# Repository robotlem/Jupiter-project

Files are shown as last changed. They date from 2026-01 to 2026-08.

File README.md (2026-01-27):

# Jupiter-project

Ziel des Projektes ist es eine fortschrittliche Lichtkonsole zu entwickeln. Diese soll künftig mit intelligenten Assistenzfunktionen ausgestattet sein.

Andere Verwendungszwecke außerhalb der Lichttechnik, beispielsweise ein Audio Playback Betrieb, oder DAW Controller sind auch denkbar.

## Ordnerinhalt

Um ein möglichst geordnetes Projekt zu erhalten soll folgende Zuordnung weitestgehend eingehalten werden.

### Datasheets

Alle möglichen Unterlagen zu den Bauteilen; z.B. Datenblätter, Anleitungen, Handbücher

### Doku

Die Dokumentation des Projektes. Was wurde wie Konfiguriert? Backups der Einstellungen/Configs. Erarbeitung eines Handbuchs zur Konsole.

### Hardware

Alle Pläne die die Hardware betreffen. Unter anderem BOM (\*Bill Of Materials\*), Konstruktionszeichnungen, ECAD, Platinendesigns, 3D-Druck Modelle, … 

### Software

Alle selbst geschriebenen Softwaremodule/-komponenten. Software für die Mikrocontroller sowie für den Mac Mini.

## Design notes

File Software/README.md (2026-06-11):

# Softwarekomponenten

Hier befinden sich die verschiedenen Softwaremodule.

Die Struktur unterteilt sich in Hardware-Modul-Software und Mac Software.

## 010_Controller_Firmware

Dieser Ordner enthält die Firmware der einzelnen Controller. Im shared ordner liegen gemeinsamme daten, wie CAN-Bus Definitionen, ...

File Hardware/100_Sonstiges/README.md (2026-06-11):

# Chain
Source: https://www.thingiverse.com/thing:4597552

Skalliert auf Y-Achse auf 137,5%

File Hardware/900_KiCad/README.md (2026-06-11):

# 900_KiCad
Dieser Ordner enthält alle zusätzlichen von KiCad benötigten Dateien:
- SW_MX.kicad_mod: Bauteildefinition für Keyswitche (MX Style) https://github.com/daprice/keyswitches.pretty.git
- SK6812-Mini-E: Aus Keebio-Parts.pretty: https://github.com/keebio/Keebio-Parts.pretty/tree/master

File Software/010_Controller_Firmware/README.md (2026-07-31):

# Jupiter Controller Firmware

Firmware-Sammlung fuer ein modulares Lichtpult, das ETC Eos auf einem Mac mini
bedient. Die Bedienhardware wie Taster, Displays, Fader und Drehencoder ist als
verteiltes System ueber einen gemeinsamen CAN-Bus angebunden. Der Mac mini
haengt ueber einen USB-CAN-Adapter ebenfalls am Bus und uebernimmt spaeter die
Uebersetzung zwischen Hardwareereignissen und Eos.

Der aktuelle Stand ist ein PlatformIO-Workspace mit mehreren separaten
Firmware-Projekten. Die Firmware fuer die einzelnen Module liegt jeweils in
einem eigenen Unterordner; gemeinsame CAN-IDs liegen in `shared/sharedCommon`.

## Projektstruktur

| Ordner | Status | Zweck |
| --- | --- | --- |
| `FM01_Pico_Encoder` | aktiv | Raspberry Pi Pico 2 / RP2350 fuer fuenf Quadratur-Encoder, zwei MCP23S17-Tasterexpander, SK6812/NeoPixel-Test und CAN ueber `can2040`. |
| `FM02_ESP_Fader` | Prototyp | ESP32-S3-Firmware fuer Motorfader mit analoger Positionsmessung, Moving Average und PI/PID-artiger Motorregelung ueber DRV8833. Noch ohne CAN-Anbindung. |
| `FM03_ESP_Display` | aktiv/prototypisch | ESP32-S3-Displaymodul mit 800x480 RGB-Panel, LovyanGFX, LVGL und CAN-Textupdates ueber ESP-IDF-TWAI. |
| `PM02_ESP_Haptic_Encoder` | Prototyp | ESP32-S3-Firmware fuer haptische Encoder mit SimpleFOC, AS5600-Magnetsensor, BLDC-Treiber und LED-Test. CAN ist vorbereitet, aber auskommentiert. |
| `shared/sharedCommon` | aktiv | PlatformIO-Library mit zentralen CAN-Konstanten in `CAN_IDs.h`. |
| `ZZZZ_legacy` | Altstand | Aeltere Tests, Proof-of-Concepts und historische Kopien. Nicht als aktuelle Quelle behandeln. |

## Toolchain

Alle aktiven Projekte verwenden PlatformIO mit Arduino-Framework.

```bash
pio run -d FM01_Pico_Encoder -e encoder_1
pio run -d FM01_Pico_Encoder -e encoder_2
pio run -d FM02_ESP_Fader
pio run -d FM03_ESP_Display -e display_1
pio run -d FM03_ESP_Display -e display_2
pio run -d PM02_ESP_Haptic_Encoder
```

Upload und serieller Monitor laufen entsprechend ueber PlatformIO:

```bash
pio run -d FM01_Pico_Encoder -e encoder_1 -t upload
pio device monitor -d FM01_Pico_Encoder -b 115200
```

Die ESP32-S3-Projekte aktivieren USB-CDC im Build, daher erscheint die serielle
Konsole typischerweise direkt ueber den USB-Port.

## CAN-Bus

Die zentrale Protokolldatei ist:

```text
shared/sharedCommon/src/CAN_IDs.h
```

Aktuelle Busparameter:

| Parameter | Wert |
| --- | --- |
| CAN-Frameformat | Standard-ID, 11 Bit |
| Bitrate | 500 kbit/s |
| Heartbeat-Intervall | 3000 ms |
| Heartbeat-Timeout | 5000 ms |

Die kleinere CAN-ID hat auf dem Bus hoehere Prioritaet.

### Button-Events

| CAN-ID | Bedeutung |
| --- | --- |
| `0x200` bis `0x20F` | `CID_BUTTON_EVENT_GRP0` bis `CID_BUTTON_EVENT_GRP15` |

Laut Kommentar wird als Payload eine Buttonnummer erwartet; bei gedruecktem
Button ist das MSB gesetzt. In `FM01_Pico_Encoder` werden die beiden MCP23S17
bereits gelesen, Button-Events werden aber im aktuellen Code noch nicht auf den
CAN-Bus gesendet.

### Display-Kommandos

| CAN-ID | Name | Payload |
| --- | --- | --- |
| `0x501` | `CID_DISPLAY_SET_TEXT_HEADER` | `Display_ID`, `Text_ID`, `Text_Length` |
| `0x500` | `CID_DISPLAY_SET_TEXT_PAYLOAD` | bis zu 8 Bytes UTF-8-Text |
| `0x502` | `CID_DISPLAY_SET_BOX_COLOR` | `Display_ID`, `Box_ID`, `R`, `G`, `B` |
| `0x503` | `CID_DISPLAY_UPDATE` | `Display_ID`; `255` aktualisiert alle Displays |

`FM03_ESP_Display` implementiert Text-Header, Payload und Update. Die
Textdaten werden in einem lokalen Buffer gesammelt und erst mit
`CID_DISPLAY_UPDATE` sichtbar gemacht. `CID_DISPLAY_SET_BOX_COLOR` ist im Code
als Case vorhanden, aber noch nicht implementiert.

Die Display-UI ist in fuenf Sektionen mit jeweils 16 Label-IDs organisiert.
Eine `Text_ID` besteht praktisch aus `section * 16 + labelIndex`, gueltig von
`0x00` bis `0x4F`.

### Heartbeats

| CAN-ID | Modul |
| --- | --- |
| `0x700` | Mac / Host |
| `0x701` | RP Pico Encoder 0 |
| `0x702` | RP Pico Encoder 1 |
| `0x703` | ESP Fader 0 |
| `0x704` | ESP Fader 1 |
| `0x705` | ESP Display 0 |
| `0x706` | ESP Display 1 |
| `0x707` | ESP Keyboard |
| `0x708` bis `0x70A` | ESP Haptic 0 bis 2 |

## Modulstatus

### FM01 Pico Encoder

Das Pico-Modul ist aktuell der am weitesten integrierte Firmwarestand:

- Zielplattform: Raspberry Pi Pico 2 (`rpipico2`) mit Earle Philhower Arduino-Core.
- Zwei Build-Varianten: `encoder_1` und `encoder_2`; `encoder_2` setzt `SECOND_ENCODER`.
- Fuenf Quadratur-Encoder werden ueber PIO gelesen.
- CAN laeuft ueber `can2040` auf PIO0 mit 500 kbit/s.
- Heartbeat sendet je nach Build-Variante `0x701` oder `0x702`.
- Zwei MCP23S17 an SPI sind initialisiert, mit Hardware-Adressierung `0x00` und `0x01`.
- 32 SK6812/NeoPixel-LEDs werden aktuell mit Testfarben gesetzt.

Bekannte Einschraenkungen:

- Encoderpositionsaenderungen werden bisher nur seriell ausgegeben, nicht als CAN-Event gesendet.
- MCP23S17-Zustandsaenderungen werden seriell ausgegeben, aber noch nicht in `CID_BUTTON_EVENT_*` Frames umgesetzt.
- `src/config.h` enthaelt noch `CAN_BUS_BITRATE = 125000`; verwendet wird aber `CAN_BITRATE = 500000` aus `sharedCommon`.
- Der CAN-Empfang puffert nur die zuletzt empfangene Nachricht. Wenn mehrere Frames vor dem Auslesen eintreffen, kann eine aeltere Nachricht ueberschrieben werden.

Weitere Details stehen in `FM01_Pico_Encoder/README.md`. Dort ist der Build-
Abschnitt allerdings aelter als die aktuelle `platformio.ini`; die aktuellen
Environments heissen `encoder_1` und `encoder_2`.

### FM02 ESP Fader

Der Fader-Code ist ein lokaler Motorregelungs-Prototyp:

- Zielplattform: ESP32-S3 DevKitC-1 mit 32 MB Flash / 16 MB PSRAM-Konfiguration.
- Faderposition wird analog gelesen und ueber einen Moving Average geglaettet.
- Zielposition kommt momentan ueber einzelne serielle Zeichen.
- Motoransteuerung erfolgt per PWM ueber DRV8833.
- Reglerparameter `Kp` und `Tn` werden ueber zwei analoge Eingange gelesen.
- CAN, Heartbeat und Eos-Integration sind noch nicht vorhanden.

### FM03 ESP Display

Das Displaymodul verbindet LVGL-UI mit CAN-Kommandos:

- Zielplattform: ESP32-S3 DevKitC-1 mit 4 MB Flash / 8 MB OPI-PSRAM-Konfiguration.
- Display: 800x480 RGB-Panel ueber LovyanGFX.
- UI: LVGL 8.3, fuenf Fader-/Button-Sektionen mit insgesamt 80 Labels.
- CAN: ESP32-TWAI auf `GPIO17` TX und `GPIO18` RX, 500 kbit/s.
- Zwei Build-Varianten: `display_1` und `display_2`; `display_2` setzt `SECOND_DISPLAY`.
- Heartbeat sendet je nach Build-Variante `0x705` oder `0x706`.

Bekannte Einschraenkungen:

- Farbupdates fuer Boxen sind noch nicht implementiert.
- Touch ist im Displaytreiber vorbereitet, aber aktuell nicht als Eingabe in die Anwendung integriert.
- Das Display akzeptiert Textpayloads nur nach passendem Header fuer die eigene `DISPLAY_ID`.

### PM02 ESP Haptic Encoder

Der haptische Encoder ist derzeit ein SimpleFOC-Versuchsstand:

- Zielplattform: ESP32-S3 DevKitC-1 N32R8V.
- Zwei Motor-/LED-Kanaele sind im Code angelegt, aktiv genutzt wird aktuell nur Motor 0.
- AS5600-Magnetsensor wird ueber I2C gesucht und fuer Motor 0 initialisiert.
- SimpleFOC arbeitet in Torque/Voltage-Control.
- Der Code erzeugt eine virtuelle Rastung mit 24 Zaehnen, Daempfung und virtuellen Endanschlaegen.
- CAN-Pins sind in `pins.h` definiert und TWAI-Code ist als Kommentar vorhanden, aber nicht aktiv.

## Offene naechste Schritte

- Einheitliches Eventformat fuer Encoder, Fader und haptische Encoder definieren.
- Button-Mapping der MCP23S17-Eingaenge als CAN-Frames senden.
- Host-Software fuer den Mac mini dokumentieren oder in dieses Repository aufnehmen.
- Fader-Firmware an CAN anbinden: Positions-Istwert, Zielwert, Touch/Taster und Heartbeat.
- Display-Farbkommandos (`CID_DISPLAY_SET_BOX_COLOR`) implementieren.
- CAN-Empfang auf Modulen mit hoeherer Last auf Queue/Ringbuffer erweitern.
- Legacy-Ordner nach Bedarf archivieren oder aus dem aktiven Workspace entfernen.

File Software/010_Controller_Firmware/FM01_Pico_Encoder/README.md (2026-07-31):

# FM01 Pico Encoder

Firmware für den Raspberry Pi Pico 2 mit RP2350. Das Projekt liest fünf
Quadratur-Encoder über PIO ein, kommuniziert über einen mit `can2040`
implementierten CAN-Bus und steuert eine Kette kompatibler NeoPixel-LEDs.

## Projektaufbau

- `src/main.cpp`: Initialisierung und Anwendungslogik
- `src/config.h`: Pinbelegung und grundlegende Konfiguration
- `src/can_bus.h/.cpp`: CAN-Schnittstelle, Empfangspuffer und PIO0-IRQ
- `src/can2040.c/.h`: Low-Level-CAN-Implementierung
- `lib/rp2040-encoder-library`: angepasste PIO-Encoder-Library für RP2350

## Build

Das Projekt verwendet PlatformIO:

```bash
pio run -e pico2
```

Die erzeugte Firmware liegt unter:

```text
.pio/build/pico2/firmware.uf2
```

## Pinbelegung

| Funktion | GPIO |
|---|---:|
| Encoder 0 A/B | 6 / 7 |
| Encoder 1 A/B | 8 / 9 |
| Encoder 2 A/B | 10 / 11 |
| Encoder 3 A/B | 12 / 13 |
| Encoder 4 A/B | 14 / 15 |
| CAN TX | 16 |
| CAN RX | 17 |
| NeoPixel-Daten | 2 |
| SPI SCK | 18 |
| SPI MOSI | 19 |
| SPI MISO | 20 |
| SPI CS | 21 |
| MCP0 Interrupt | 5 |
| MCP1 Interrupt | 4 |

Die beiden Signale eines Encoders müssen auf aufeinanderfolgenden GPIOs
liegen. Der in `PioEncoder` angegebene Pin ist jeweils der A-Pin.

## PIO-Belegung

Der RP2350 besitzt drei PIO-Blöcke mit jeweils vier State Machines.

| PIO | State Machine | Verwendung |
|---|---|---|
| PIO0 | SM0 | CAN Synchronisation |
| PIO0 | SM1 | CAN Empfang |
| PIO0 | SM2 | CAN Bitmustervergleich |
| PIO0 | SM3 | CAN Senden |
| PIO1 | SM0 | Encoder 0 |
| PIO1 | SM1 | Encoder 1 |
| PIO1 | SM2 | Encoder 2 |
| PIO1 | SM3 | Encoder 3 |
| PIO2 | SM0 | Encoder 4 |
| PIO2 | SM1 | NeoPixel/FastLED |
| PIO2 | SM2 | frei |
| PIO2 | SM3 | frei |

### Warum FastLED auf PIO2/SM1 liegt

Die Encoder werden zuerst initialisiert. Dadurch sind alle State Machines von
PIO1 und SM0 von PIO2 belegt. Anschließend reserviert das CAN-Modul alle vier
State Machines von PIO0. FastLED sucht danach in der Reihenfolge PIO0, PIO1,
PIO2 nach einer freien State Machine und erhält PIO2/SM1.

FastLED benötigt für die gesamte LED-Kette nur eine State Machine und einen
DMA-Kanal. Die Anzahl der LEDs erhöht die Anzahl benötigter State Machines
nicht.

### PIO-Programmspeicher

Jeder PIO-Block besitzt 32 Instruktionsplätze:

- Das Encoderprogramm benötigt 24 Instruktionen und wird pro PIO nur einmal
  geladen.
- Das FastLED-NeoPixel-Programm benötigt auf PIO2 zusätzlich 4 Instruktionen.
- PIO2 verwendet damit 28 von 32 Instruktionsplätzen.

Auf PIO2 bleiben zwei State Machines frei, aber nur vier freie
Instruktionsplätze. Ein weiteres PIO-Programm muss daher sowohl in die freien
State Machines als auch in den verbleibenden Programmspeicher passen.

## CAN-Schnittstelle

Das CAN-Modul stellt drei Funktionen bereit:

```cpp
void canBusBegin();
bool canBusReceive(CanBusMessage &message);
bool canBusTransmit(const CanBusMessage &message);
```

`canBusReceive()` liefert die zuletzt im IRQ empfangene Nachricht. Wenn vor dem
Auslesen mehrere Nachrichten eintreffen, wird die vorherige Nachricht
überschrieben; es gibt aktuell keine Software-Warteschlange.

## MCP23S17

Die Klasse `Mcp23s17` konfiguriert einen SPI-Portexpander mit 16 Eingängen,
internen Pull-ups und Interrupt bei Eingangsänderung:

```cpp
#include "mcp23s17.h"

Mcp23s17 mcp0;
Mcp23s17 mcp1;

void setup() {
    mcp0.init(0, PIN_MCP0_INT);
    mcp1.init(1, PIN_MCP1_INT);
}

void loop() {
    const uint16_t inputs0 = mcp0.update();
    const uint16_t inputs1 = mcp1.update();
}
```

Die Adresse entspricht dem Zustand der Hardware-Adresspins `A2:A0` und muss
zwischen `0` und `7` liegen. Alle MCP23S17 teilen sich den in `config.h`
definierten Chip-Select-Pin; die Auswahl erfolgt über die aktivierte
Hardware-Adressdekodierung.

Der Rückgabewert von `update()` enthält `GPIOA` in Bit 0 bis 7 und `GPIOB` in
Bit 8 bis 15. Wegen der Pull-ups ist ein offener Eingang `1` und ein gegen
Masse geschalteter Eingang `0`.

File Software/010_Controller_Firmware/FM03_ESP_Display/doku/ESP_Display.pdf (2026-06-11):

# ESP_Display

Version 1.0 (28.05.2026)

Hier die Ideen zur Gestaltung des Displays.

Das Display ist, wie alle anderen Module, über ein CAN-Bus Interface angebunden. Als erstes Ziel soll die Firmware nur Daten anzeigen können, eine Option für Touchinputs und Rückmeldung an das Host-Programm soll aber offen gelassen werden.

Da die Text- und Gestaltungsdaten (z.B. Farben) mehr als 8-Byte (Maximale Framelänge im Standard CAN-Bus) lang sind ist es nötig ein Format zu wählen, das die Daten in mehreren Frames schickt. Dankbarerweise ist bei CAN bereits eine Datensicherungsschicht vorhanden, sodass man sich nur noch um einen Header kümmern muss, der die textId (informationen darüber, an welcher Stelle der Text steht) und die Länge des Textes enthält. Genaueres zu textIds und deren Aufbau weiter unten.

## Standard Bildschirm

Standard Bildschirm

16 Zeilen in 5 Spalten
In Hex durchnummeriert

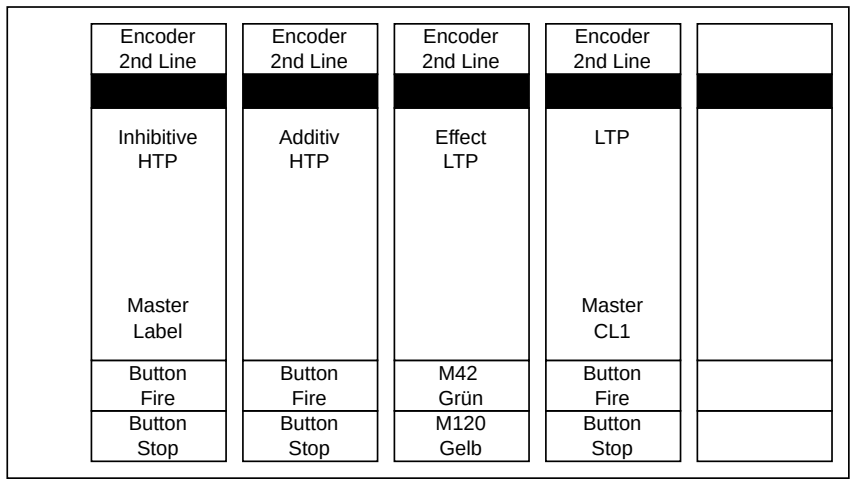
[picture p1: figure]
Encoder 2nd Line; Button Stop; Button Fire; Inhibitive HTP; Master Label; Additiv HTP; M120 Gelb; M42 Grün; Effect LTP; LTP; Master CL1
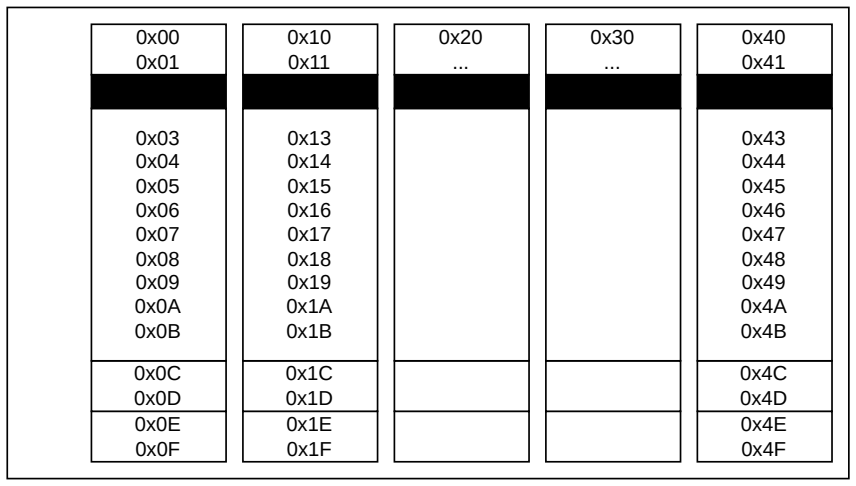
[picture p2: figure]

CAN Frame

Setzen der Kästen

Auch die Kästen haben IDs, mit denen Parameter wie Farbe gesetzt werden können

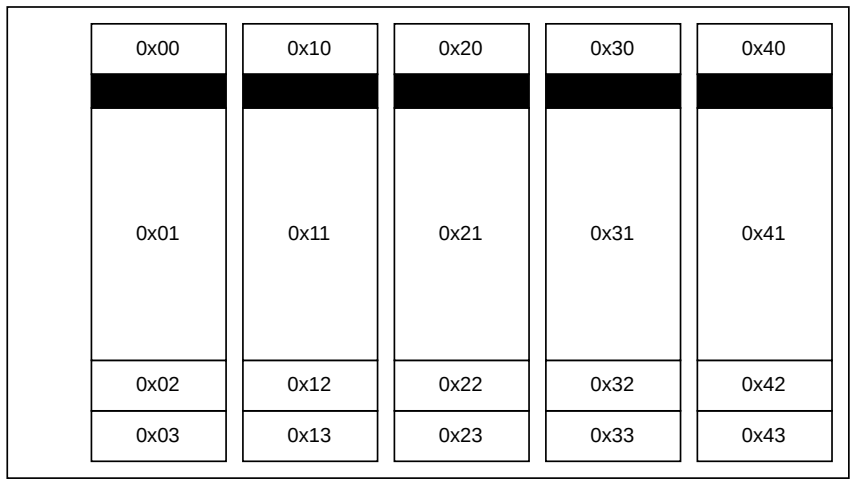
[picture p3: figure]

CAN Frame

CID_DISPLAY_SET_BOX_COLOR | Display_ID | Box_ID | R | G | B

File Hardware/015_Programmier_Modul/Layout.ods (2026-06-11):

Live | Snapshot |  | Help |  |  |  |  |  |  |  | Live | Blind | Stage
Blind | Fader |  | Address/ Patch |  |  |  |  |  |  |  | Displays |  | System
Stage | Macro |  | Learn | SK1 | SK2 | SK3 | SK4 | SK5 | SK6 | More SK | Undo |  | Scroll Lock
Displays |  |  |  | Query | Copy To | Recall From | Label |  | About | Park | Escape | PgUp | Select
System | Delete | Path | Effect | GoTo Cue | Block | Assert | Offset | High | Fan | Capture | PgLeft | PgDown | PgRight
M 801 | Part | Cue | Record | + | Thru | - | / | Mark | Sneak | Select Last | Tab | Find | Time
M 802 | Int Palette | Focus Palette | Record Only | 7 | 8 | 9 | Rem Dim | + % | Home | Select Manual | Format | Expand | Delta
M 803 | Color Palette | Beam Palette | Update | 4 | 5 | 6 | Out | - % | Trace | Select Active
M 804 | Preset | Sub | Group | 1 | 2 | 3 | Full | Level | Q Only Track | Last
M 805 | Shift | Delay | Time | Clear | 0 | . | At | Enter |  | Next

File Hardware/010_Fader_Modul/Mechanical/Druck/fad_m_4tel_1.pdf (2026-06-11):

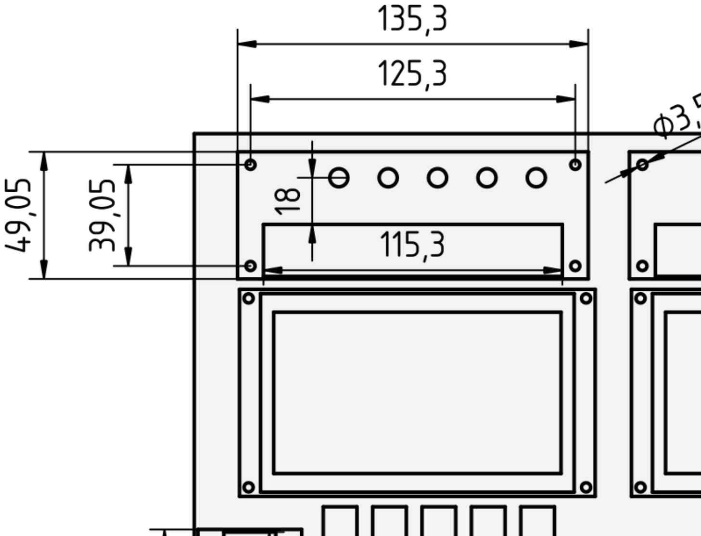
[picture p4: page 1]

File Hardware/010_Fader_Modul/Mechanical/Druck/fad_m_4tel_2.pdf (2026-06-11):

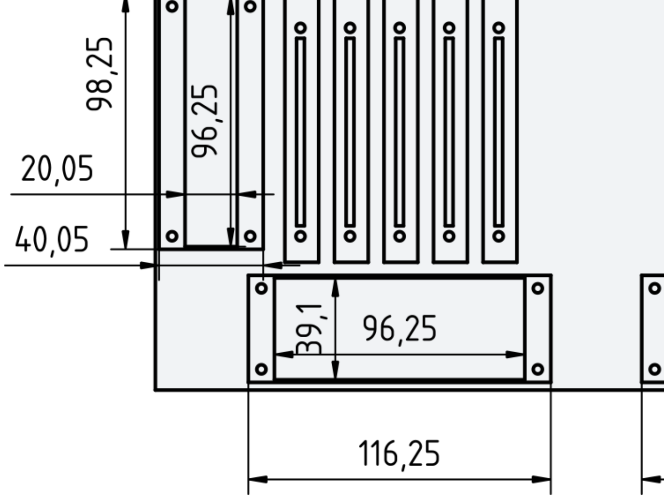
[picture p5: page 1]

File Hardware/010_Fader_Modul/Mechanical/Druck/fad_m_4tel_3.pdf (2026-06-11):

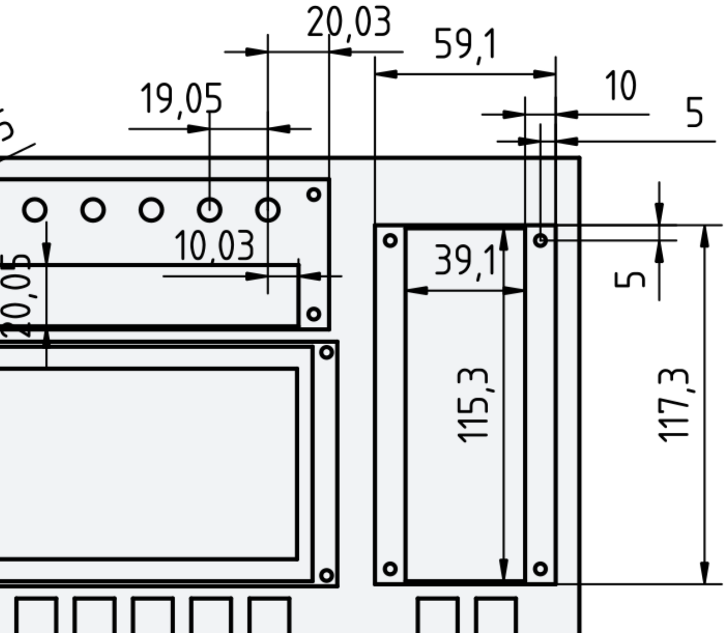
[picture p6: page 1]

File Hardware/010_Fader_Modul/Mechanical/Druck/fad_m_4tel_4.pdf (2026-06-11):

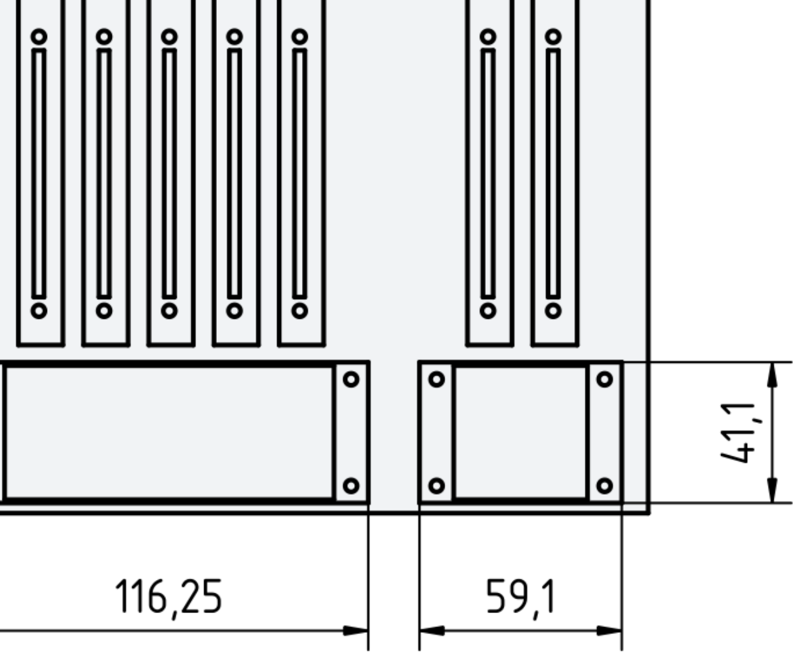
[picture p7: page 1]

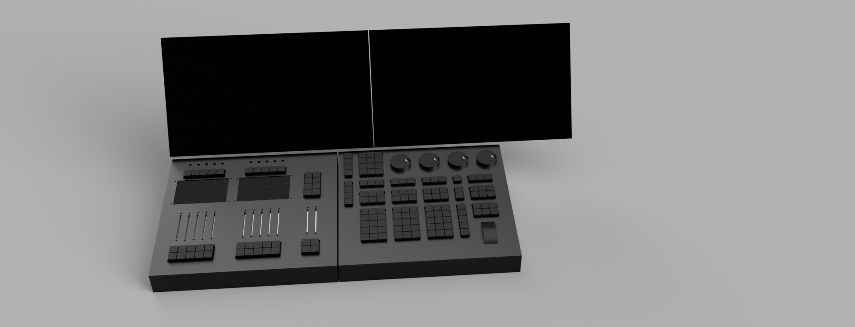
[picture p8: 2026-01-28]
Hardware/000_Uebersicht/9bad7475-ef7c-4377-8133-a8e182cbd2e1.PNG

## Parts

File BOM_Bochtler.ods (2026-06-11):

Bauteil | Artikelnummer | Anzahl | Preis stk. | Preis ges. |  | Händler | Link
Motorfader | 652-PSM60-081A-103B2 | 13 | 16,24 € | 211,12 € |  | Mouser | https://www.mouser.de/ProductDetail/652-PSM60-081A-103B2
Keyswitche | 540-MX3A-11NA | 170 | 0,86 € | 146,20 € |  | Mouser | https://www.mouser.de/ProductDetail/CHERRY/MX3A-11NA?qs=F5EMLAvA7ICizK1XKjfN9w%3D%3D
IO Expander | 579-MCP23S17-E/SO | 12 | 1,45 € | 17,40 € |  | Mouser | https://www.mouser.de/ProductDetail/Microchip-Technology/MCP23S17-E-SO?qs=usxtMOJb1RzJScThsWtScg%3D%3D
ESP32 S3 | 356-32S3DKTC1N32R16V | 6 | 13,66 € | 81,96 € |  | Mouser | https://www.mouser.de/ProductDetail/Espressif-Systems/ESP32-S3-DevKitC-1-N32R16V
Drehencoder | 652-PEC11R-4020F-N24 | 15 | 1,38 € | 20,70 € |  | Mouser | https://www.mouser.de/ProductDetail/Bourns/PEC11R-4020F-N0024?qs=Zq5ylnUbLm4a1Xa9DSXVvA%3D%3D
 |  |  |  | 0,00 €
 |  |  |  | 0,00 €
 |  |  |  | 0,00 €
 |  |  |  | 0,00 €
 |  |  |  | 0,00 €
 |  |  |  | 0,00 €
 |  |  |  | 0,00 €
 |  |  |  | 0,00 €
 |  |  |  | 477,38 €
 |  |  |  | + 19% | 568,08 € |  | (evtl. Zölle)

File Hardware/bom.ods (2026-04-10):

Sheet: Sheet1
 | Bauteil | Anzahl | Preis stk | Preis ges | Status
Grundlegend
 | Mac Mini (M4, 16GB RAM, 265GB SSD) | 1 | 579,00 € | 579,00 € | gekauft | apple.com → Studentenrabatt
 | Monitor Touch, 21,5“ | 2 | 266,67 € | 533,34 € | gekauft | https://www.galaxus.de/de/s1/product/iiyama-prolite-t2255msc-b1-1920-x-1080-pixel-2150-monitor-30378827
 | Anschlusskabel | 2 | 0,00 € | 0,00 € | inklusive
 | Tastatur | 1 | 53,99 € | 53,99 € | gekauft | https://www.amazon.de/dp/B0G3GK968S?ref=ppx_yo2ov_dt_b_fed_asin_title&th=1
 | USB C Hub | 1 | 8,99 € | 8,99 € | gekauft | https://www.amazon.de/dp/B07Q29N6H1?ref=ppx_yo2ov_dt_b_fed_asin_title&th=1
 | USB C auf B Kabel | 1 | 5,99 € | 5,99 € | gekauft | https://www.amazon.de/dp/B0DGX9YTBK?ref=ppx_yo2ov_dt_b_fed_asin_title&th=1
 |  |  |  | 0,00 €
 |  |  |  |  | https://www.mouser.de/ProductDetail/CHERRY/MX3A-11NA?qs=F5EMLAvA7ICizK1XKjfN9w%3D%3D
Fader Modul |  |  |  | 0,00 €
 | Motorisierte Schiebepotentiometer | 12 | 20,00 € | 240,00 € | THAB
 | Drehimpulsgeber | 10 | 2,00 € | 20,00 € | THAB | 652-PEC11R-4020F-N24
 | Keyswitche | 48 |  | 39,99 € | THAB | https://www.amazon.de/Glorious-Gaming-mechanische-Raptor-Tastaturschalter/dp/B0DCPFBS57?th=1 | 110
 | Motortreiber DRV8833 | 6 |  | 6,99 € |  | https://www.amazon.de/DRV8833-2-Kanal-DC-Motorantriebsplatine-Motorantriebs-Eingangsspannung/dp/B0DHRFRG6X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
 | MCP23S17 IO Expander | 3 | 1,53 € | 4,59 € | THAB
 | WS2812B | 48 |  | siehe unten | gekauft | https://www.amazon.de/SEZO-Individuell-Adressierbar-Nicht-Wasserdicht-Inneneinrichtung/dp/B09N99DJRG | 300
 | Weitere ICs, PCBs, Stecker, Kabel,... |  |  | 100,00 €
 |  |  |  | 0,00 €
Programming Modul |  |  |  | 0,00 €
 | Streamdeck | 1 | 199,00 € | 199,00 € | gekauft
 | Drehimpulsgeber | 5 | 2,00 € | 10,00 € | THAB
 | MCP23S17 IO Expander | 6 | 1,53 € | 9,18 € | THAB | https://www.mouser.de/ProductDetail/Microchip-Technology/MCP23S17-E-SP?qs=usxtMOJb1RyzobAZrBjFZA%3D%3D
 |  |  |  | 0,00 €
 |  |  |  | 0,00 €
 |  |  |  | 0,00 €
 | Keyswitche |  |  | 39,99 € |  | https://www.amazon.de/Glorious-Gaming-mechanische-Raptor-Tastaturschalter/dp/B0DCPFBS57?th=1 | 110
 | WS2812B |  |  | 22,99 € | gekauft | https://www.amazon.de/SEZO-Individuell-Adressierbar-Nicht-Wasserdicht-Inneneinrichtung/dp/B09N99DJRG
 | Weitere ICs, PCBs, Stecker, Kabel... | 1 | 100,00 € | 100,00 €
Gehäuse | Siebdruckplatten | 5 | 36,95 € | 184,75 € | gekauft
 | Vierkantrohr 25x25x2000 | 2 | 22,90 € | 45,80 € | gekauft
 | Vierkantrohr 20x20x2000 | 1 | 7,50 € | 7,50 € | gekauft
 | Flachstahl 30x6x2000 | 1 | 9,40 € | 9,40 € | gekauft
 | Schlossschrauben M8 | 1 | 6,59 € | 6,59 € | gekauft
 | Einfacauszug | 1 | 11,29 € | 11,29 € | gekauft
 | Nieten 4,8mm | 1 | 8,19 € | 8,19 € | gekauft
 | Nieten 4,8mm | 1 | 6,99 € | 6,99 € | gekauft
 | Nieten 4,8mm | 1 | 6,99 € | 6,99 € | gekauft
 | Sonstiges Case | 1 | 149,15 € | 149,15 € | gekauft
 | Servo Motoren | 1 | 11,99 € | 11,99 € | gekauft
 |  |  |  | 0,00 €
 |  |  |  | 0,00 €
 |  |  | Summe | 2.422,68 €
 |  |  |  |  |  | -422,68 €

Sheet: Sheet2
Case |  |  | stk | preis stk | summe
 | Kantenprofile | AH 1m | 10 | 3,9 | 39
 | Schlließprofile | 1m | 8 | 4,5 | 36
 | Kugelecken |  | 8 | 1 | 8
 | Butterfly |  | 4 | 6,5 | 26
 | Klappgriffe |  | 2 | 4,8 | 9,6
 |  |  |  |  | 0
 |  |  |  |  | 0
 |  |  |  |  | 0
 |  |  |  |  | 0
 |  |  |  |  | 0
 |  |  |  |  | 0
 |  |  |  |  | 0
 |  |  |  |  | 0
 |  |  |  |  | 0
 |  |  |  |  | 0
 |  |  |  |  | 0
 |  |  |  |  | 0
 |  |  |  |  | 0
 |  |  |  |  | 0
 |  |  |  |  | 118,6

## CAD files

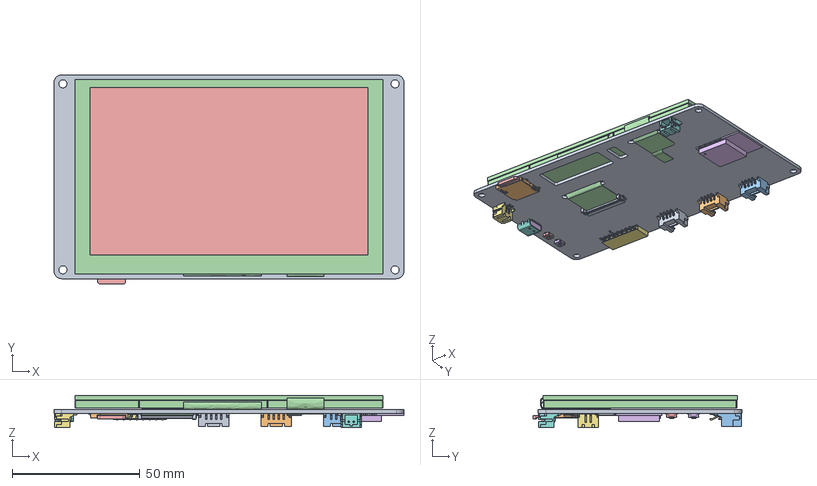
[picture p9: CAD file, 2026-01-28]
Datasheets/5Zoll_Screen.FCStd
137.2 x 82.0 x 12.6 mm
5IN-PCB-0221_A
BREP_1-383
BREP_2-384
BREP_8
BREP_9
BREP_10
BREP_11
BREP_12
BREP_13
BREP_14
BREP_15
BREP_16
BREP_17
BREP_18
BREP_19
BREP_20
BREP_21
BREP_22
BREP_23
BREP_24
BREP_25
BREP_26
BREP_27
BREP_31
BREP_33
BREP_32
BREP_034

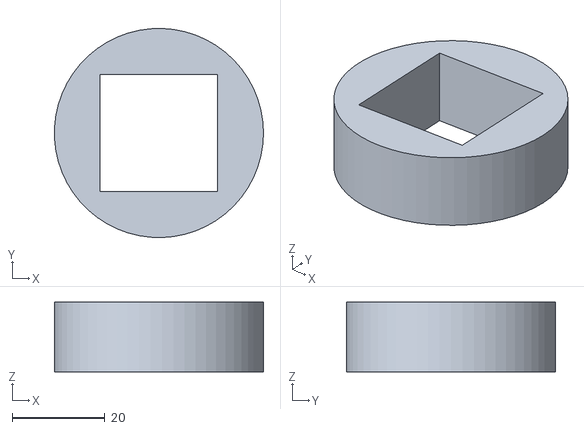
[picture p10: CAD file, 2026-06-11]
Hardware/005_Case/Fuerungen/Fuerung_Drehpunkt.stl
45.0 x 45.0 x 15.0

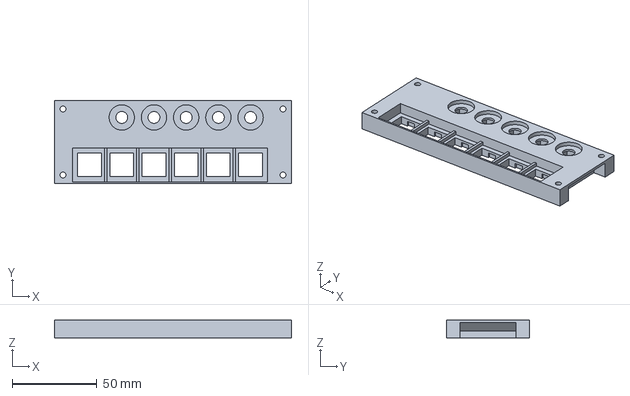
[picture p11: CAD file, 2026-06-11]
Hardware/010_Fader_Modul/Mechanical/3D-Druck/Fader_switch_holder_1x6_encoder.FCStd
140.2 x 49.0 x 10.5 mm

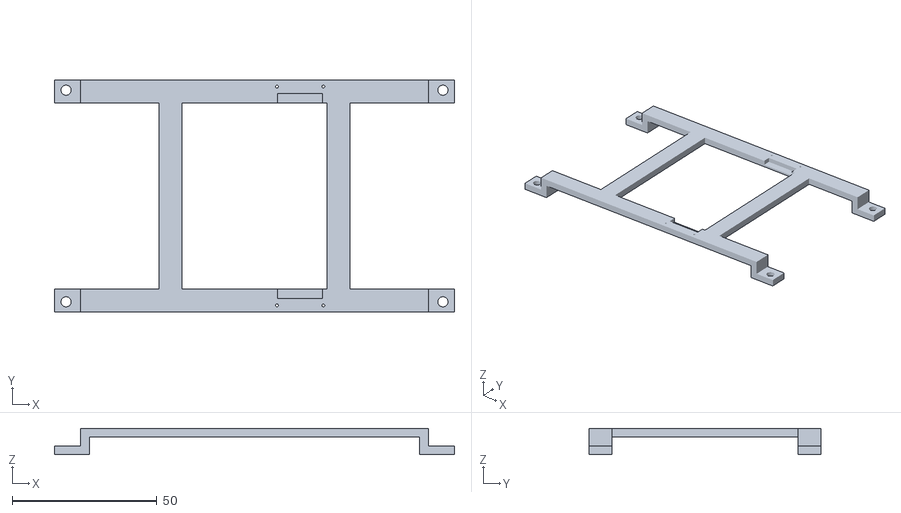
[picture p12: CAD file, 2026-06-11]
Hardware/010_Fader_Modul/Mechanical/Display_Can_adapter_holder-KörperPocket002.stl
138.0 x 80.0 x 9.00

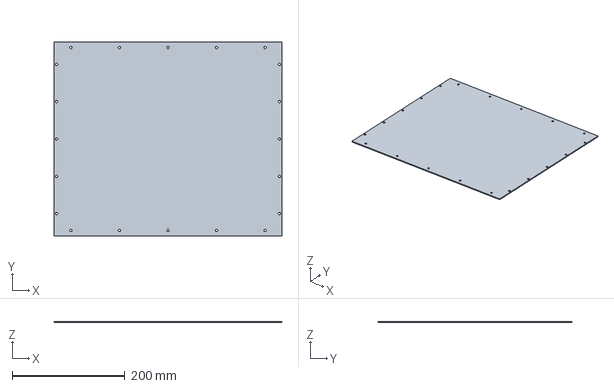
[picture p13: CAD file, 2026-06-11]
Hardware/015_Programmier_Modul/Front_plate_Programming.FCStd
405.0 x 345.0 x 2.00 mm

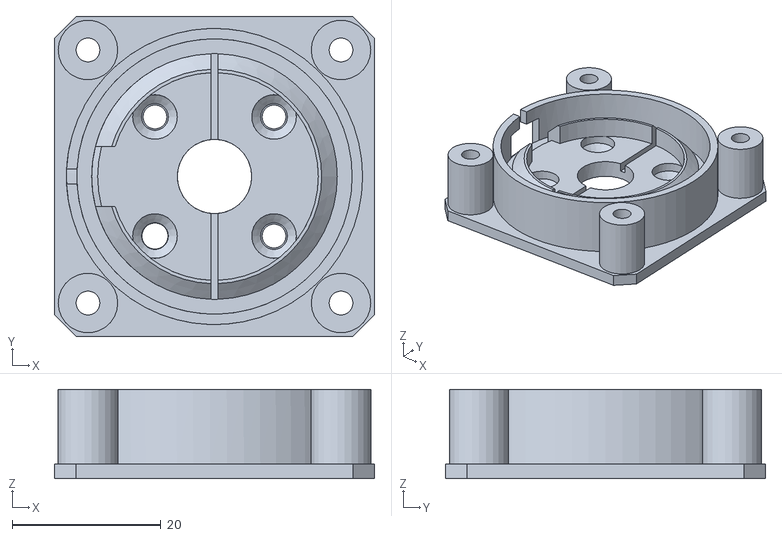
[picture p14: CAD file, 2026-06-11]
Hardware/025_Haptische_Encoder/Motorhalter_v2-1-KörperPocket008.stl
43.0 x 43.0 x 12.0

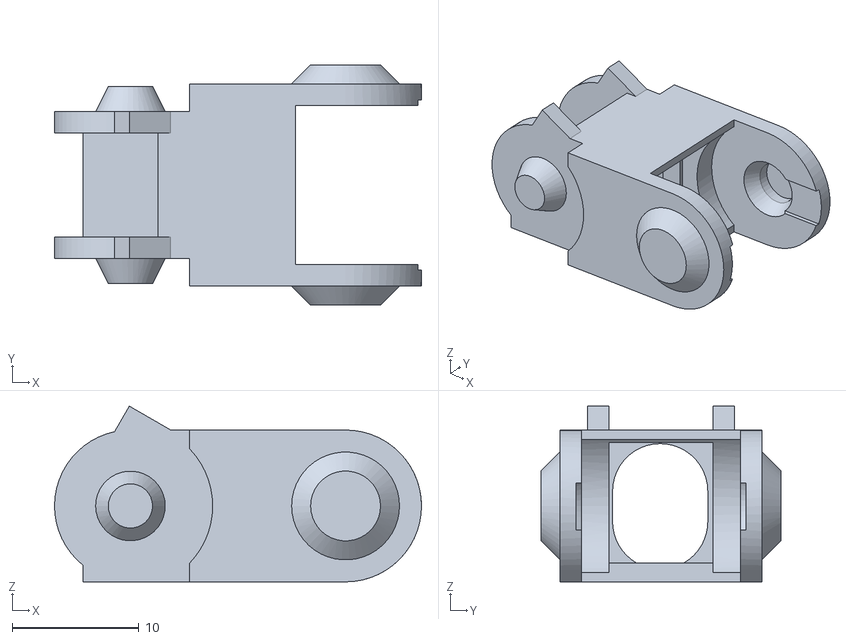
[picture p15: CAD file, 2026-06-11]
Hardware/100_Sonstiges/chain_link.stl
29.0 x 19.0 x 13.9

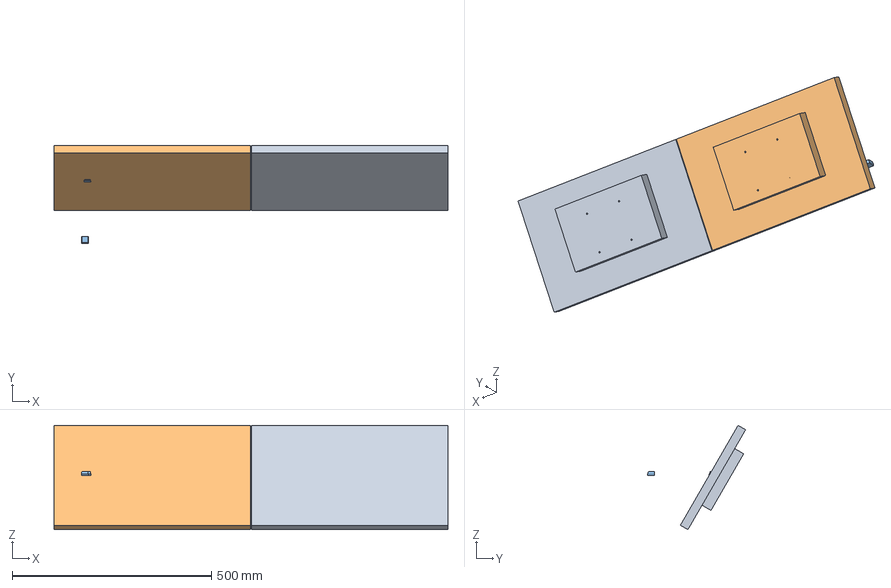
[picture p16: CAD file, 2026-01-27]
Hardware/Overview.FCStd
988.3 x 246.4 x 261.6 mm
Touchscreen1
Touchscreen2
keycap x 2

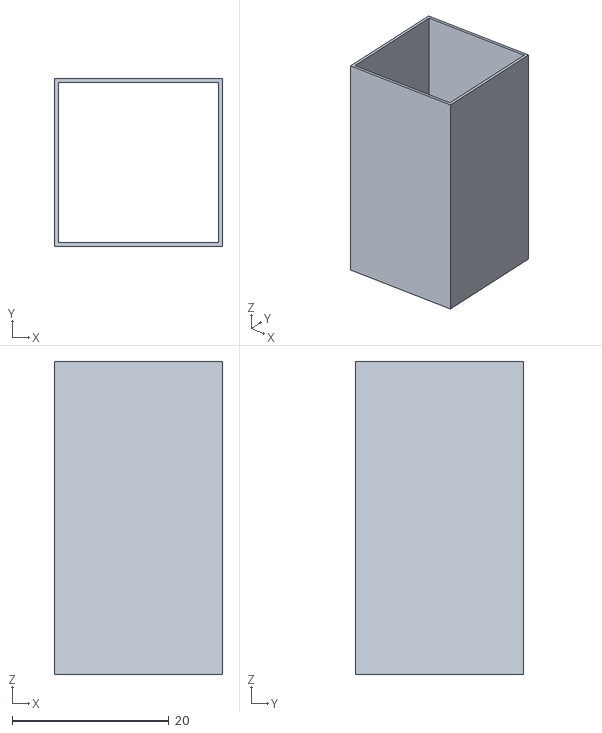
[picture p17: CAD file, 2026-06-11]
Hardware/005_Case/Fuerungen/Fuehrung_neu.stl
21.5 x 21.5 x 40.0

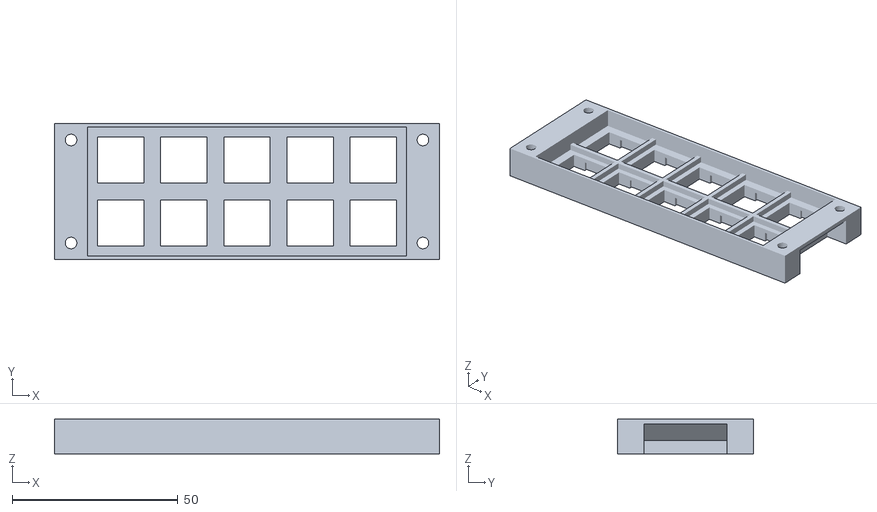
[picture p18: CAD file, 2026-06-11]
Hardware/010_Fader_Modul/Mechanical/3D-Druck/Fader_switch_holder-Körper001Chamfer.stl
116.2 x 41.1 x 10.5

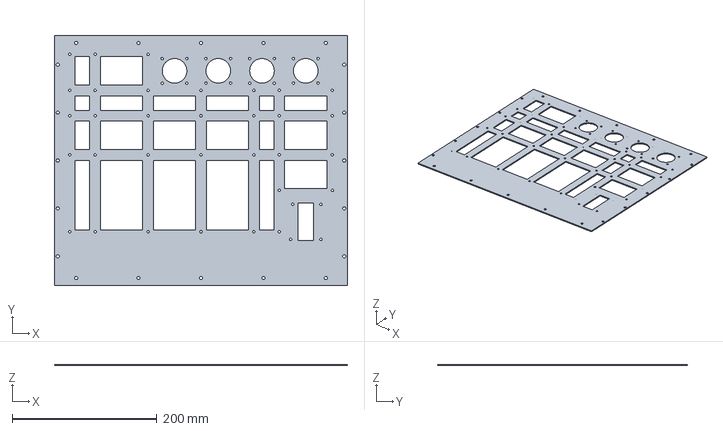
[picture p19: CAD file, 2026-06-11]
Hardware/015_Programmier_Modul/Front_plate_Programming_holes_only.FCStd
405.0 x 345.0 x 2.00 mm

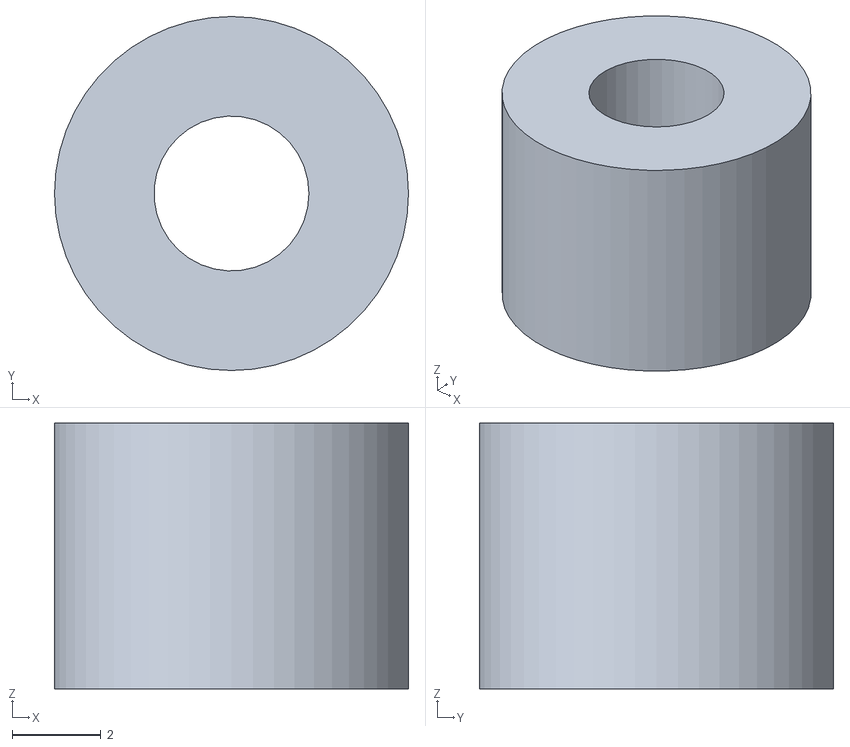
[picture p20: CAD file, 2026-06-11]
Hardware/025_Haptische_Encoder/spacer.stl
8.00 x 8.00 x 6.00

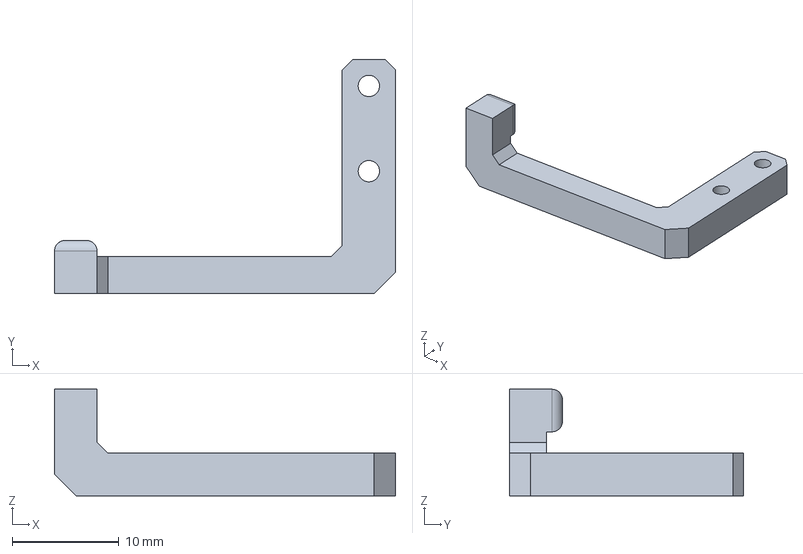
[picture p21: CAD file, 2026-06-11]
Hardware/100_Sonstiges/Mac_mini_servo_arm_2.FCStd
32.0 x 22.0 x 10.0 mm

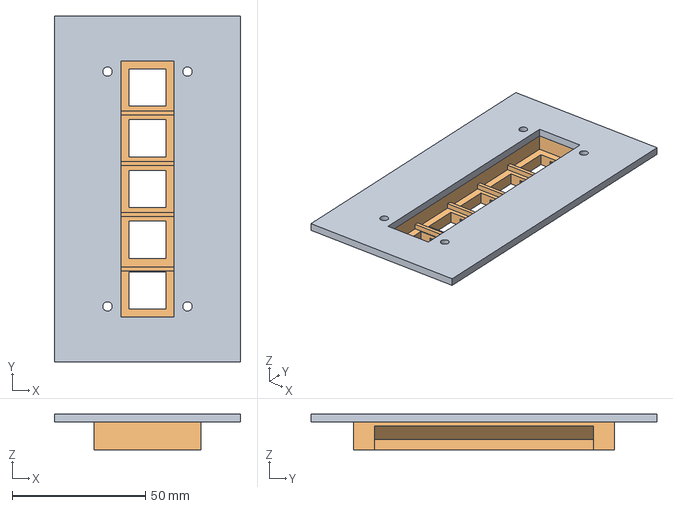
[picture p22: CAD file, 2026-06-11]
Hardware/010_Fader_Modul/Mechanical/3D-Druck/Fader_switch_holder_1x5.FCStd
70.0 x 130.0 x 13.5 mm
Körper
Körper001

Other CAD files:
Hardware/010_Fader_Modul/Mechanical/Display_Can_adapter_holder.FCStd
Hardware/005_Case/Fuerungen/Fuerung_neu.FCStd
Hardware/010_Fader_Modul/Mechanical/Front_plate_version2.FCStd
Hardware/015_Programmier_Modul/Programming_plate.dxf
Hardware/000_Uebersicht/Uebersicht.f3d
Hardware/005_Case/Fuerungen/Fuerung_Drehpunkt_v2.stl
Hardware/005_Case/Fuerungen/Fuerung_Gross.stl
Hardware/005_Case/Fuerungen/Fuerung_Klein.stl
Hardware/005_Case/Fuerungen/Fuerung_neu.stl
Hardware/005_Case/Fuerungen/Fuerungen.FCStd
Hardware/005_Case/Fuerungen/Fuerungen_Drehpunkt.stl
Hardware/010_Fader_Modul/Mechanical/3D-Druck/Fader_switch_holder.FCStd
Hardware/010_Fader_Modul/Mechanical/3D-Druck/Fader_switch_holder_1x5-Körper001Chamfer.stl
Hardware/010_Fader_Modul/Mechanical/3D-Druck/Fader_switch_holder_1x6_encoder-KörperChamfer.stl
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

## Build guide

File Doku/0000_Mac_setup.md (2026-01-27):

# Setup des Mac Mini

Es handelt sich um einen Mac Mini (2024) in der Basisausstattung (16GB RAM, 256GB SSD)

## Installierte Programme

- homebrew
- firefox
- touch-base Touchscreen Treiber (OEM Version) https://www.touch-base.com/oem/weida/
- texstudio
- mactex
- etc EOS
- spotify
- nextcloud client
- git
- Qt, Qt creator über Qt Online Installer
- CLion
- gcc
- Xcode: Ansonsten läuft qt nicht
- FreeCad

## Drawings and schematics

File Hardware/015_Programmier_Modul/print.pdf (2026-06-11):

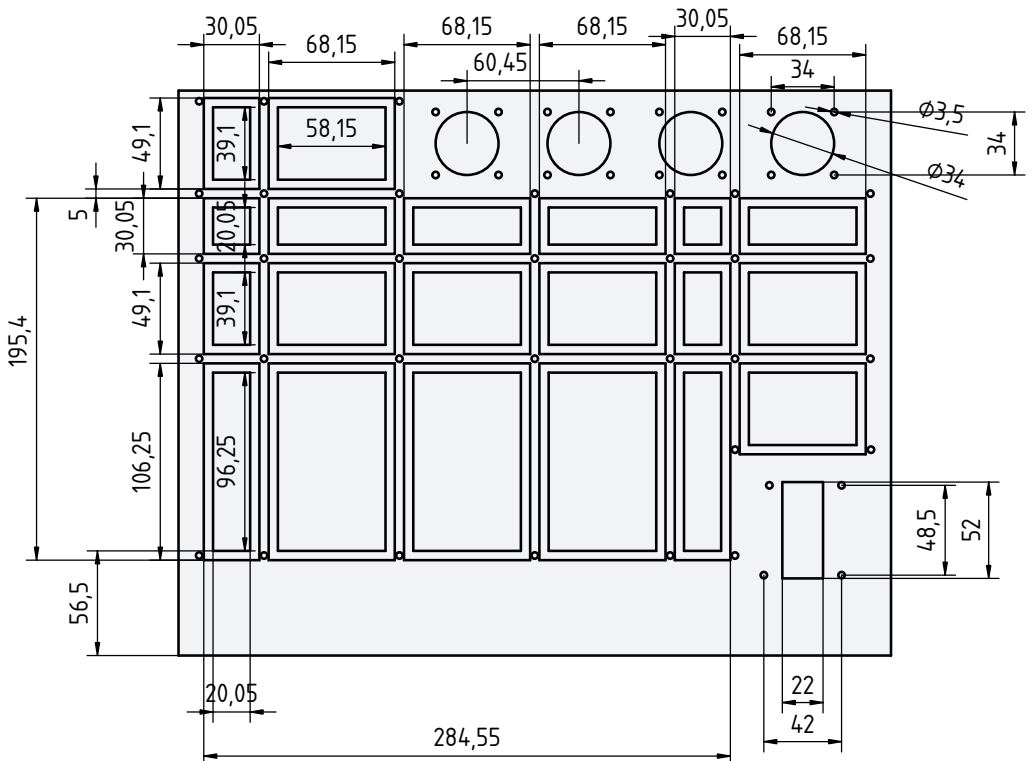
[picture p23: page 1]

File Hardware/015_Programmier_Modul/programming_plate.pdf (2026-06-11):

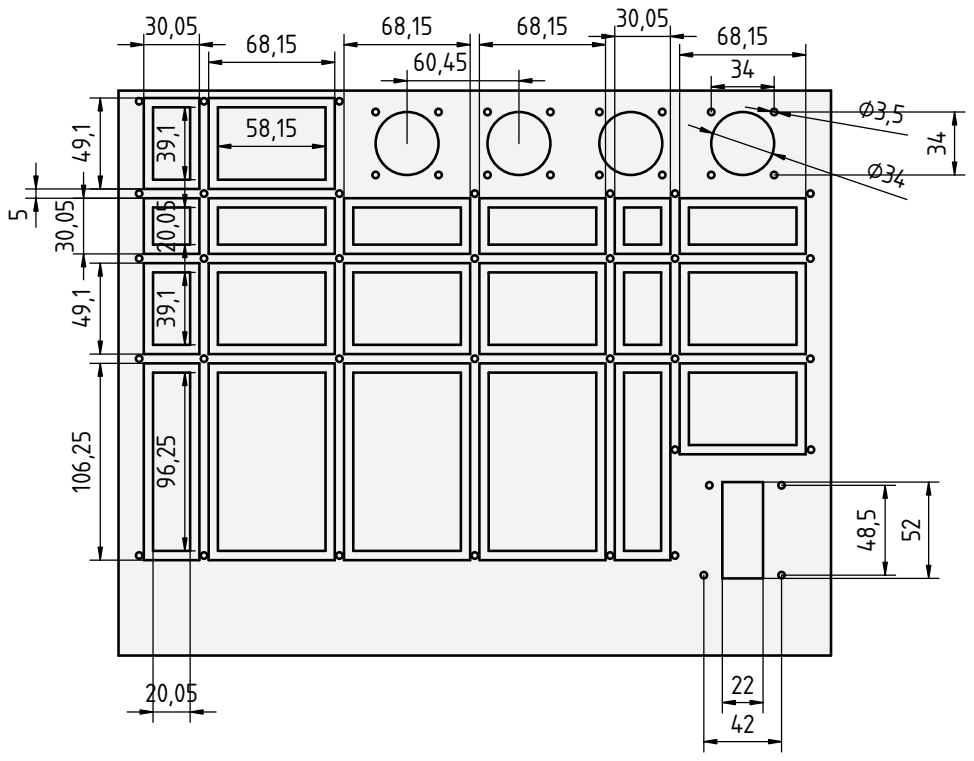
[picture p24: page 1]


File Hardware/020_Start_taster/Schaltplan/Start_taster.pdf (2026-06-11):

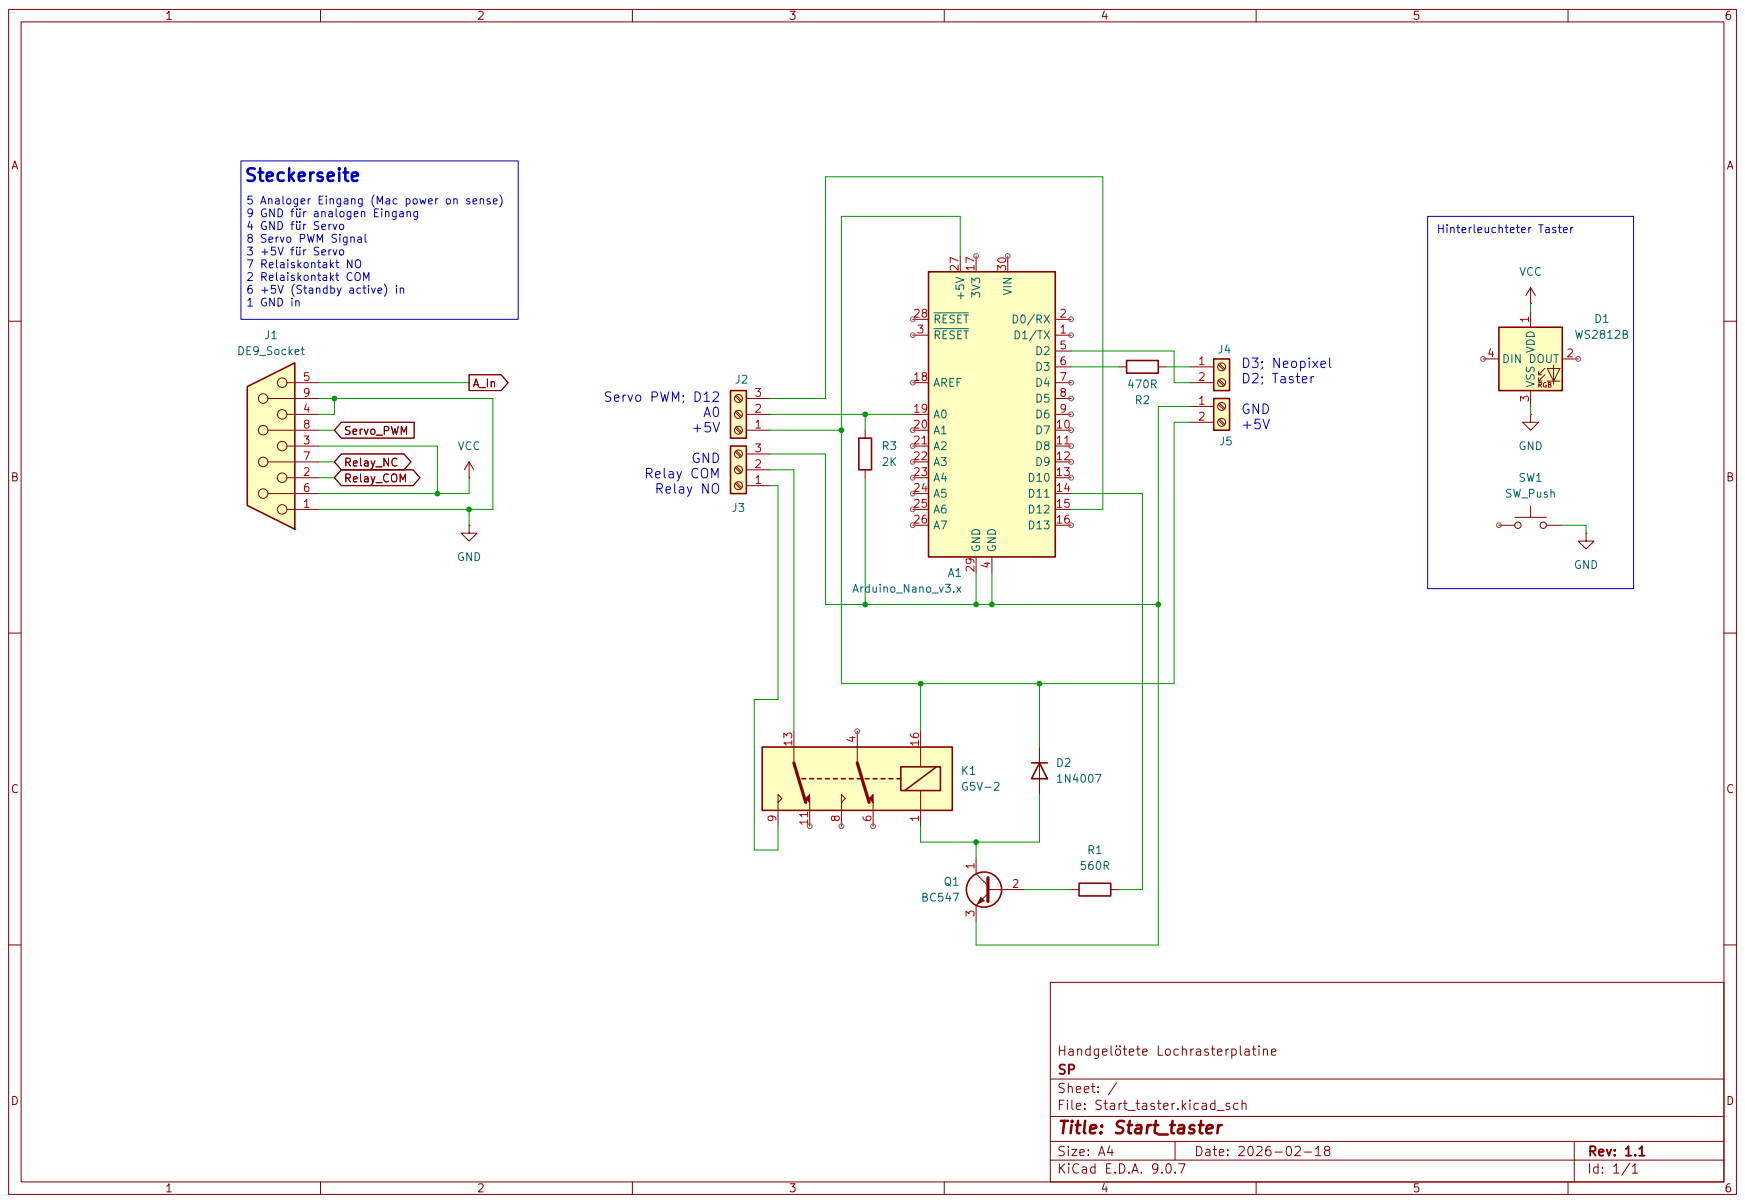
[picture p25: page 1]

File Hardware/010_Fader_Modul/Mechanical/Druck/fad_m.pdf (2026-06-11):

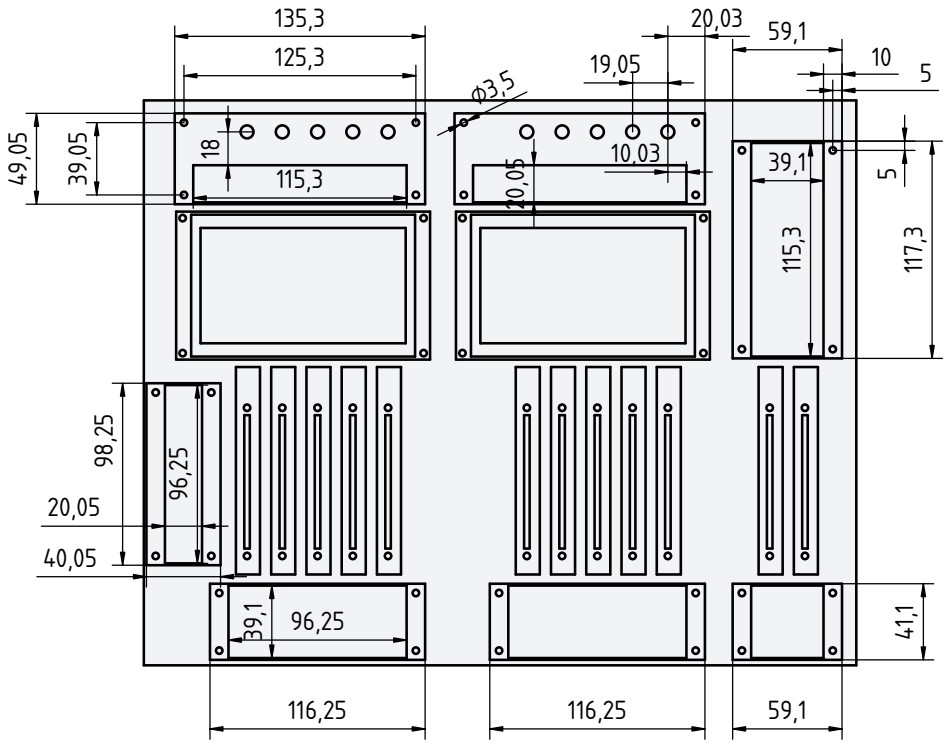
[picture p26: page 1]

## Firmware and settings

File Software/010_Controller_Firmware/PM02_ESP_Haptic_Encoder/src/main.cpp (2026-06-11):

#include <Arduino.h>
#include <FastLED.h>
#include <SimpleFOC.h>
//#include "driver/twai.h"
#include "pins.h"

#define NUM_LEDS 16

BLDCMotor motor0 = BLDCMotor(7);
BLDCDriver3PWM driver0 = BLDCDriver3PWM(DRV0_IN1, DRV0_IN2, DRV0_IN3, DRV0_EN);
MagneticSensorI2C sensor0 = MagneticSensorI2C(0x36, 12, 0x0E, 4);

BLDCMotor motor1 = BLDCMotor(7);
BLDCDriver3PWM driver1 = BLDCDriver3PWM(DRV1_IN1, DRV1_IN2, DRV1_IN3, DRV1_EN);
MagneticSensorI2C sensor1 = MagneticSensorI2C(0x36, 12, 0x0E, 4);

TwoWire I2C_0 = TwoWire(0);
TwoWire I2C_1 = TwoWire(1);

CRGB leds0[NUM_LEDS];
CRGB leds1[NUM_LEDS];

void setup() {
// write your initialization code here
    Serial0.begin(115200);

    FastLED.addLeds<NEOPIXEL, LED0_OUT>(leds0, NUM_LEDS);
    FastLED.addLeds<NEOPIXEL, LED1_OUT>(leds1, NUM_LEDS);

    for (int i = 0; i < NUM_LEDS; i++) {
        leds0[i] = CRGB::Green;
        leds1[i] = CRGB::Blue;

    }
    FastLED.setBrightness(255);

    FastLED.show();


    // twai_general_config_t g_config = TWAI_GENERAL_CONFIG_DEFAULT(CAN_TX, CAN_RX, TWAI_MODE_NORMAL);
    // twai_timing_config_t t_config = TWAI_TIMING_CONFIG_500KBITS();  // Baudrate anpassen
    // twai_filter_config_t f_config = TWAI_FILTER_CONFIG_ACCEPT_ALL();
    // if (twai_driver_install(&g_config, &t_config, &f_config) != ESP_OK) {
    //     Serial0.println("TWAI install failed!");
    //     return;
    // }
    // if (twai_start() != ESP_OK) {
    //     Serial0.println("TWAI start failed!");
    //     return;
    // }
    // Serial0.println("CAN ready!");

    I2C_0.begin(I2C0_SDA, I2C0_SCL, 100000);
    //I2C_1.begin(I2C1_SDA, I2C1_SCL, 100000);

    for(uint8_t addr=1; addr<127; addr++) {
        I2C_0.beginTransmission(addr);
        uint8_t err = I2C_0.endTransmission();

        if(err == 0) {
            Serial.printf("Found I2C device: 0x%02X\n", addr);
        }
    }

    SimpleFOCDebug::enable(&Serial0);

    sensor0.init(&I2C_0);
    motor0.linkSensor(&sensor0);
    //sensor1.init(&I2C_1);
    //motor1.linkSensor(&sensor1);

    driver0.voltage_power_supply = 12;
    driver0.init();
    motor0.linkDriver(&driver0);
    // driver1.voltage_power_supply = 12;
    // driver1.init();
    // motor1.linkDriver(&driver1);

    motor0.controller = MotionControlType::torque;
    motor0.torque_controller = TorqueControlType::voltage;
    // motor1.controller = MotionControlType::torque;
    // motor1.torque_controller = TorqueControlType::voltage;

    motor0.monitor_downsample = 50; // disable intially
    motor0.monitor_variables = _MON_TARGET | _MON_VEL | _MON_ANGLE; // monitor target velocity and angle
    motor0.voltage_limit = 6;
    motor0.velocity_limit = 10;
    motor0.P_angle.P = 2;   // kleiner = weicher
    // motor1.monitor_downsample = 50; // disable intially
    // motor1.monitor_variables = _MON_TARGET | _MON_VEL | _MON_ANGLE; // monitor target velocity and angle
    // motor1.voltage_limit = 6;
    // motor1.velocity_limit = 10;
    // motor1.P_angle.P = 2;   // kleiner = weicher

    motor0.PID_velocity.P = 0.15;
    motor0.PID_velocity.I = 0.5;
    motor0.PID_velocity.D = 0.0;
    motor0.LPF_velocity.Tf = 0.05;
    // motor1.PID_velocity.P = 0.15;
    // motor1.PID_velocity.I = 0.5;
    // motor1.PID_velocity.D = 0.0;
    // motor1.LPF_velocity.Tf = 0.05;


    // initialise motor
    // if (!motor0.initFOC()) {
    //     Serial0.println("motor0 FOC init FAILED");
    //     while(1);
    // }
    // if (!motor1.initFOC()) {
    //     Serial0.println("motor1 FOC init FAILED");
    //     while(1);
    // }

    // align encoder and start FOC
    motor0.initFOC();
    motor0.target = motor0.shaft_angle;
    // motor1.initFOC();
    // motor1.target = motor1.shaft_angle;



}

void loop() {
// write your code here


    motor0.loopFOC();

    float angle = motor0.shaft_angle;
    float velocity = motor0.shaft_velocity;

    float torque = 0;

    // Beispiel: 24 Rastungen
    int teeth = 24;
    float step = _2PI / teeth;
    float nearest = round(angle / step) * step;
    float error = angle - nearest;
    torque = - error*error * 120.0;
    if (error < 0) torque = -torque;

    // leichte Dämpfung
    torque -= velocity * 0.02;

    // virtuelle Endanschläge
    float limit = 2 * _2PI;
    float wall_stiffness = 40.0;

    if (angle > limit) {
        torque = -(angle - limit) * wall_stiffness;
    }

    if (angle < -limit) {
        torque = -(angle + limit) * wall_stiffness;
    }



    torque = constrain(torque, -motor0.voltage_limit, motor0.voltage_limit);
    motor0.move(torque);

    //
    //
    // {
    //     motor1.loopFOC();
    //
    //     float angle = motor1.shaft_angle;
    //     float velocity = motor1.shaft_velocity;
    //
    //     float torque = 0;
    //
    //     // Beispiel: 24 Rastungen
    //     int teeth = 24;
    //     float step = _2PI / teeth;
    //     float nearest = round(angle / step) * step;
    //     float error = angle - nearest;
    //     torque = - error*error * 120.0;
    //     if (error < 0) torque = -torque;
    //
    //     // leichte Dämpfung
    //     torque -= velocity * 0.02;
    //
    //     // virtuelle Endanschläge
    //     float limit = 2 * _2PI;
    //     float wall_stiffness = 40.0;
    //
    //     if (angle > limit) {
    //         torque = -(angle - limit) * wall_stiffness;
    //     }
    //
    //     if (angle < -limit) {
    //         torque = -(angle + limit) * wall_stiffness;
    //     }
    //
    //
    //
    //     torque = constrain(torque, -motor1.voltage_limit, motor1.voltage_limit);
    //     motor1.move(torque);
    // }
}

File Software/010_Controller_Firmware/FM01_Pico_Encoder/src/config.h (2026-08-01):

//
// Created by robo on 19.05.26.
//

#ifndef ZA_TEST_ENCODER_RPI_CONFIG_H
#define ZA_TEST_ENCODER_RPI_CONFIG_H

#include "Arduino.h"
#include <CAN_IDs.h>

// --- CAN CONFIGURATION ---    // CAN Läuft auf PIO 0
const int CAN_TX_PIN = 16;           // Beliebige freie GPIOs wählbar
const int CAN_RX_PIN = 17;

#ifdef SECOND_ENCODER
const uint16_t  CID_ENCODER_EVENT   = CID_ENCODER_EVENT_GRP1;
const uint16_t  CID_BUTTON_EVENT    = CID_BUTTON_EVENT_GRP1;
const uint16_t  CID_HEARTBEAT       = CID_HEARTBEAT_RPI_ENCODER_1;
#else
const uint16_t  CID_ENCODER_EVENT   = CID_ENCODER_EVENT_GRP0;
const uint16_t  CID_BUTTON_EVENT    = CID_BUTTON_EVENT_GRP0;
const uint16_t  CID_HEARTBEAT       = CID_HEARTBEAT_RPI_ENCODER_0;
#endif

// --- Encoder Configuration ---
const uint8_t PIN_ENC0 = 6;     // PIO 1
const uint8_t PIN_ENC1 = 8;     // PIO 1
const uint8_t PIN_ENC2 = 10;    // PIO 1
const uint8_t PIN_ENC3 = 12;    // PIO 1

const uint8_t PIN_ENC4 = 14;    // PIO 2
//Encoder Update Intervall in encoder.h

// --- SPI Configuration ---
const uint8_t PIN_SPI_SCK  = 18;
const uint8_t PIN_SPI_MOSI = 19;
const uint8_t PIN_SPI_MISO = 20;
const uint8_t PIN_SPI_CS   = 21;

// --- MCP23S17 Configuration ---
const uint8_t PIN_MCP0_INT = 5;
const uint8_t PIN_MCP1_INT = 4;

// --- SK6812 Mini-E Configuration ---
const uint8_t LED_PIN = 2;

// How to get the Index of the local LED Array from LED_ID?
// 1. Check for range: if (LED_ID-LED_OFFSET > LED_MAX_ID || LED_ID-LED_OFFSET < 0) return;
// 2. Get local Array Index: LED_MAPPING(LED_ID - LED_OFFSET)
// Check Result: 255 = invalid

#ifdef SECOND_ENCODER
const uint8_t NUM_LEDS = 32;
const uint8_t LED_OFFSET = 0;
const uint8_t LED_MAX_ID = 52;
const uint8_t LED_MAPPING[] = {
// 0    1    2    3    4      5    6    7    8    9
  255, 255, 255, 255, 255,   255,   0,   1,   2,   3, //  0 -   9
    4,   5, 255, 255, 255,   255, 255, 255, 255, 255, // 10 -  19
   255, 255, 255, 255, 255,  255, 255,  22,  23,  24, // 20 -  29
    25,  26,  27,  28,  29,   30,  31,   6,   7,   8, // 30 -  39
     9,  10,  11,  12,  13,   14,  15,  16,  17,  18, // 40 -  49
    19,  20,  21
};
#else
const uint8_t NUM_LEDS = 27;
const uint8_t LED_OFFSET = 0;
const uint8_t LED_MAX_ID = 26;
const uint8_t LED_MAPPING[] = {
      0,   1,   2,   3,   4,     5, 255, 255, 255, 255, //  0 -   9
    255, 255,   6,   7,   8,     9,  10,  11,  12,  13, // 10 -  19
     14,  15,  16,  17,  18,    19,  20, 255, 255, 255  // 20 -  29
};
#endif

#endif //ZA_TEST_ENCODER_RPI_CONFIG_H

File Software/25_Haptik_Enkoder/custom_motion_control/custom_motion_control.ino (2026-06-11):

#include <Arduino.h>
#include <SimpleFOC.h>

#define PID_vel_P
#define PID_vel_I
#define PID_vel_D


BLDCMotor motor = BLDCMotor(7);
//BLDCDriver3PWM driver = BLDCDriver3PWM(19, 18, 5, 17);
//MagneticSensorI2C sensor = MagneticSensorI2C(0x36, 12, 0x0E, 4);

BLDCDriver3PWM driver = BLDCDriver3PWM(14, 13, 12, 11);
MagneticSensorI2C sensor = MagneticSensorI2C(0x36, 12, 0x0E, 4);

void setup() {
  //Wire.begin(21, 22); 
  Wire.begin(41, 42); 
  Wire.setClock(400000);

  Serial.begin(115200);
  SimpleFOCDebug::enable(&Serial);

  // initialize sensor hardware
  sensor.init();
  motor.linkSensor(&sensor);

  // driver config
  driver.voltage_power_supply = 12;
  driver.init();
  motor.linkDriver(&driver);

  // set control loop type to be used
  motor.controller = MotionControlType::torque;
  motor.torque_controller = TorqueControlType::voltage;

  // comment out if not needed
  //motor.useMonitoring(Serial);
  motor.monitor_downsample = 50; // disable intially
  motor.monitor_variables = _MON_TARGET | _MON_VEL | _MON_ANGLE; // monitor target velocity and angle
  motor.voltage_limit = 6;
  motor.velocity_limit = 10;
  motor.P_angle.P = 2;   // kleiner = weicher

  motor.PID_velocity.P = 0.15;
  motor.PID_velocity.I = 0.5;
  motor.PID_velocity.D = 0.0;

  motor.LPF_velocity.Tf = 0.05;

  // initialise motor
  motor.init();

  // align encoder and start FOC
  motor.initFOC();
  motor.target = motor.shaft_angle;


  _delay(1000);
}

void loop() {
  // iterative setting FOC phase voltage
  motor.loopFOC();

  float angle = motor.shaft_angle;
  float velocity = motor.shaft_velocity;

  float torque = 0;

  // Beispiel: 24 Rastungen
  int teeth = 24;
  float step = _2PI / teeth;
  float nearest = round(angle / step) * step;
  float error = angle - nearest;
  torque = - error*error * 120.0;
  if (error < 0) torque = -torque;

  // leichte Dämpfung
  torque -= velocity * 0.02;

  // virtuelle Endanschläge
  float limit = 2 * _2PI;
  float wall_stiffness = 40.0;

  if (angle > limit) {
    torque = -(angle - limit) * wall_stiffness;
  }

  if (angle < -limit) {
    torque = -(angle + limit) * wall_stiffness;
  }
  


  torque = constrain(torque, -motor.voltage_limit, motor.voltage_limit);
  motor.move(torque);


}

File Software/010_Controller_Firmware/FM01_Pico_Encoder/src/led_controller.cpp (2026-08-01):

#include "led_controller.h"

#include <CAN_IDs.h>

#include "config.h"

LedController::LedController(CRGB leds[], uint8_t ledCount) {
    this->leds = leds;
    this->ledCount = ledCount <= NUM_LEDS ? ledCount : NUM_LEDS;
}

void LedController::begin() {
    FastLED.addLeds<NEOPIXEL, LED_PIN>(leds, ledCount);
    FastLED.setBrightness(255);
    fill_solid(pendingColors, ledCount, CRGB::Black);
    fill_solid(activeColors, ledCount, CRGB::Black);
    fill_solid(renderedColors, ledCount, CRGB::Black);
    fill_solid(leds, ledCount, CRGB::Black);
    blinkStartMs = millis();
    warningBlinkStartMs = blinkStartMs;
    lastHostHeartbeatMs = blinkStartMs;
    nextBlinkRenderMs = blinkStartMs;
    FastLED.show();
}

void LedController::update() {
    const unsigned long now = millis();
    updateHostHeartbeatState(now);

    if (static_cast<long>(now - nextBlinkRenderMs) < 0) {
        return;
    }

    nextBlinkRenderMs = now + BLINK_RENDER_INTERVAL_MS;
    if (renderOutputState(now)) {
        FastLED.show();
    }
}

bool LedController::handleCanMessage(const CanBusMessage &message) {
    switch (message.id) {
        case CID_LED_SET_INDIVIDUAL:
            setIndividual(message);
            return true;
        case CID_LED_SET_GROUP:
            setGroup(message);
            return true;
        case CID_LED_SET_INDI_BLINKMODE:
            setIndividualBlinkMode(message);
            return true;
        case CID_LED_SET_GROUP_BLINKMODE:
            setGroupBlinkMode(message);
            return true;
        case CID_LED_SYNC_BLINKMODE:
            blinkStartMs = millis();
            nextBlinkRenderMs = blinkStartMs;
            if (renderOutputState(blinkStartMs)) {
                FastLED.show();
            }
            return true;
        case CID_LED_UPDATE:
            commitPendingState();
            return true;
        case CID_HEARTBEAT_MAC:
            handleHostHeartbeat();
            return true;
        default:
            return false;
    }
}

void LedController::setIndividual(const CanBusMessage &message) {
    if (message.length < 2) {
        return;
    }

    const uint8_t startLedId = message.data[0];
    for (uint8_t i = 1; i < message.length; i++) {
        setLed(static_cast<uint16_t>(startLedId) + i - 1, message.data[i]);
    }
}

void LedController::setIndividualBlinkMode(const CanBusMessage &message) {
    if (message.length < 2) {
        return;
    }

    const uint8_t startLedId = message.data[0];
    for (uint8_t i = 1; i < message.length; i++) {
        setLedBlinkMode(static_cast<uint16_t>(startLedId) + i - 1, message.data[i]);
    }
}

void LedController::setGroup(const CanBusMessage &message) {
    if (message.length < 2) {
        return;
    }

    const uint8_t startGroupId = message.data[0];
    for (uint8_t i = 1; i < message.length; i++) {
        setGroupColor(static_cast<uint16_t>(startGroupId) + i - 1, message.data[i]);
    }
}

void LedController::setGroupBlinkMode(const CanBusMessage &message) {
    if (message.length < 2) {
        return;
    }

    const uint8_t startGroupId = message.data[0];
    for (uint8_t i = 1; i < message.length; i++) {
        setGroupBlinkMode(static_cast<uint16_t>(startGroupId) + i - 1, message.data[i]);
    }
}

void LedController::setGroupColor(uint16_t groupId, uint8_t colorIntens) {
    const LedGroup *group = findGroup(groupId);
    if (group == nullptr) {
        return;
    }

    for (uint8_t i = 0; i < group->ledCount; i++) {
        setLed(group->ledIds[i], colorIntens);
    }
}

void LedController::setGroupBlinkMode(uint16_t groupId, uint8_t blinkMode) {
    const LedGroup *group = findGroup(groupId);
    if (group == nullptr) {
        return;
    }

    for (uint8_t i = 0; i < group->ledCount; i++) {
        setLedBlinkMode(group->ledIds[i], blinkMode);
    }
}

void LedController::setLed(uint16_t ledId, uint8_t colorIntens) {
    uint8_t localIndex = 0;
    if (!mapLedId(ledId, localIndex) || localIndex >= ledCount) {
        return;
    }

    pendingColors[localIndex] = decodeColor(colorIntens);
}

void LedController::setLedBlinkMode(uint16_t ledId, uint8_t blinkMode) {
    uint8_t localIndex = 0;
    if (!mapLedId(ledId, localIndex) || localIndex >= ledCount) {
        return;
    }

    pendingBlinkModes[localIndex] = blinkMode;
}

const LedGroup *LedController::findGroup(uint16_t groupId) {
    for (uint8_t i = 0; i < LED_GROUP_COUNT; i++) {
        if (LED_GROUPS[i].groupId == groupId) {
            return &LED_GROUPS[i];
        }
    }

    return nullptr;
}

void LedController::commitPendingState() {
    if (leds == nullptr) {
        return;
    }

    for (uint8_t i = 0; i < ledCount; i++) {
        activeColors[i] = pendingColors[i];
        activeBlinkModes[i] = pendingBlinkModes[i];
    }

    renderOutputState(millis());
    FastLED.show();
}

void LedController::handleHostHeartbeat() {
    const unsigned long now = millis();
    lastHostHeartbeatMs = now;

    if (!hostOffline) {
        return;
    }

    hostOffline = false;
    nextBlinkRenderMs = now;
    if (renderOutputState(now)) {
        FastLED.show();
    }
}

void LedController::updateHostHeartbeatState(unsigned long now) {
    if (hostOffline || static_cast<unsigned long>(now - lastHostHeartbeatMs) <= HEARTBEAT_TIMEOUT) {
        return;
    }

    hostOffline = true;
    warningBlinkStartMs = now;
    nextBlinkRenderMs = now;
    if (renderOutputState(now)) {
        FastLED.show();
    }
}

bool LedController::renderOutputState(unsigned long now) {
    if (leds == nullptr) {
        return false;
    }

    bool changed = false;
    for (uint8_t i = 0; i < ledCount; i++) {
        const CRGB rendered = hostOffline ? renderWarningLed(i, now) : renderLed(i, now);
        if (rendered != renderedColors[i]) {
            renderedColors[i] = rendered;
            leds[i] = rendered;
            changed = true;
        }
    }

    return changed;
}

CRGB LedController::renderLed(uint8_t localIndex, unsigned long now) const {
    const uint8_t scale = blinkScale(activeBlinkModes[localIndex], now - blinkStartMs);
    return scaleColor(activeColors[localIndex], scale);
}

CRGB LedController::renderWarningLed(uint8_t localIndex, unsigned long now) const {
    if (localIndex != 0) {
        return CRGB::Black;
    }

    const uint8_t warningBlinkMode = LED_BLINKMODE_MID | LED_BLINKMODE_FADE_IN | LED_BLINKMODE_FADE_OUT;
    const uint8_t scale = blinkScale(warningBlinkMode, now - warningBlinkStartMs);
    const CRGB yellow = decodeColor(INTENS_ID_7 | COLOR_ID_YELLOW);
    return scaleColor(yellow, scale);
}
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

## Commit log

2026-01-27 First commit on Macos
    [Overview.FCStd, bom.ods]
2026-01-28 Erstes Fusion360 Modell
    [5Zoll_Screen.FCStd, Uebersicht.f3d]
2026-04-10 LCD works
    [bom.ods]
2026-06-11 vor der anpassung vom rpi encoder code
    [BOM_Bochtler.ods, Display_Can_adapter_holder-KörperPocket002.stl, Display_Can_adapter_holder.FCStd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]
2026-06-11 Drehencoder funktionieren mit RPI Pico 2 (RP2350)
2026-07-29 Extended some of the CAN Protocol and prepared Config for RPI Encoders
2026-07-31 Pico Encoder update (CAN)
2026-08-01 Pico Encoder nearly finished
2026-08-01 Pico Encoder host timeout eingebaut
2026-08-01 Pico Encoder fertig. Version 1.0
